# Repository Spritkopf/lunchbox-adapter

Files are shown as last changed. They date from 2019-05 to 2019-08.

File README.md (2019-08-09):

# Introduction

This is my interpretation of the *BrotboxErsatzPlatine* instrument adapter for the BMW K100. It is based on the circuit originally created by Maru (maru-labs.com).
Its purpose is to replace the original instrument unit of the BMW K100 (affectionately called *lunchbox* because of its distinctive shape) with 3rd party speedometer units. For more information have a look at maru-labs.com.
I extended the circuit according to my own needs and put together my own circuit board.

This project consists of the KiCAD design files for the schematic and PCB

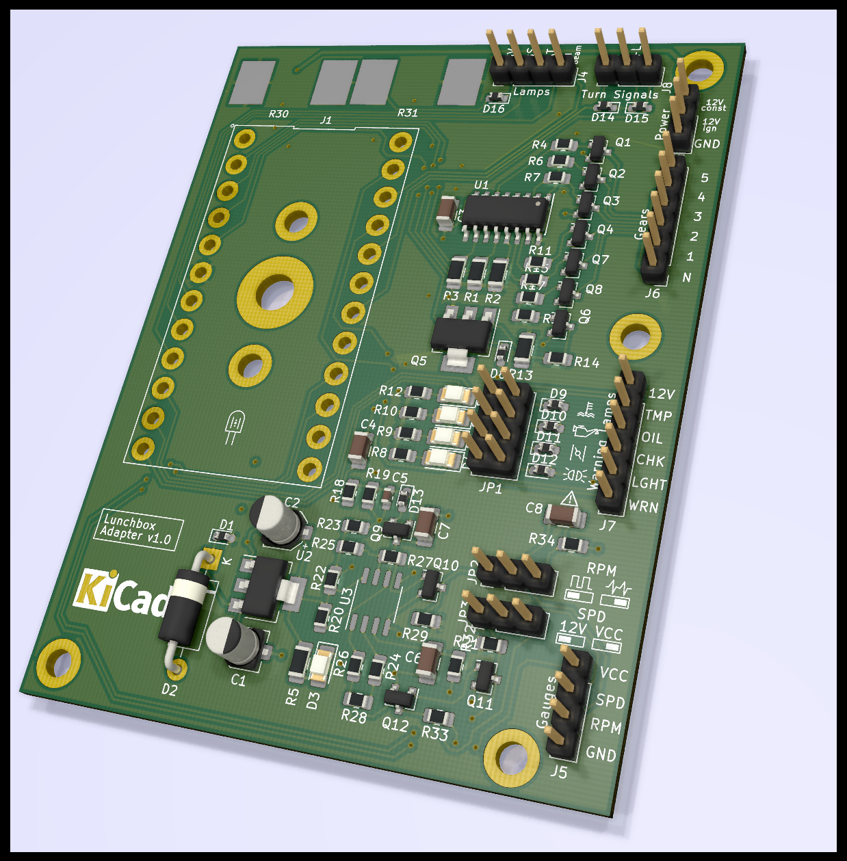
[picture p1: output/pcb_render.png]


# Features

* Plugs into the stock connector for the K100 instrument unit
* Convert signal of the original speed sensors to a square wave signal understood by most 3rd party speedos
* Conditioning of primary ignition coil RPM signal and conversion to square wave signal understood by most 3rd party speedos
* Provide excitation current for alternator
* Combine several of the information/warning lights to a common warning light output
* supports gear indicator (one wire for every gear)

## Speed signal voltage

The output voltage of the speed signal can be selected between 12V and a custom supply voltage at PIN1 (VCC) on the Gauges Connector (J5) by setting the jumper JP3 to the appropriate position

## RPM signal waveform

Depending on the type of tacho unit, the output waveform of the RPM signal can be selected between 12V Square wave (pulses to ground) and a sort of cleaned up raw ignition signal by setting jumper JP2 to the appropriate position. The square wave signal should be standard, the latter option is just there as an experiment.

## Warning lights

The warning lights for temperature (TMP), oil pressure (OIL), choke (CHK) and Light-test (LGHT) are displayed by individual LEDs on the board. Additionally, any number of them can be grouped together to a general warning lamp (WRN) if your dashboard has no space for this many lamps. Each of the 4 rows of Jumper JP1 can be bridged to select this warning signal to the general warning lamp. Please be aware that if only the general warning lamp is used you have no information on the source of the warning other than looking at the smd LEDs on the board.

# Credits

Thanks to maru (maru-labs.com) for the general idea. I re-used a lot of the circuit of the original BEP.
Thanks to user `robmack` from k100-forum.com from whom I stole the RPM conditioning circuit.

# No warranty

I created this as a hobby project as an experiment / exercise. I will not be responsible for any damage caused to your bike by using all of or parts of this circuit. Use at your own risk.

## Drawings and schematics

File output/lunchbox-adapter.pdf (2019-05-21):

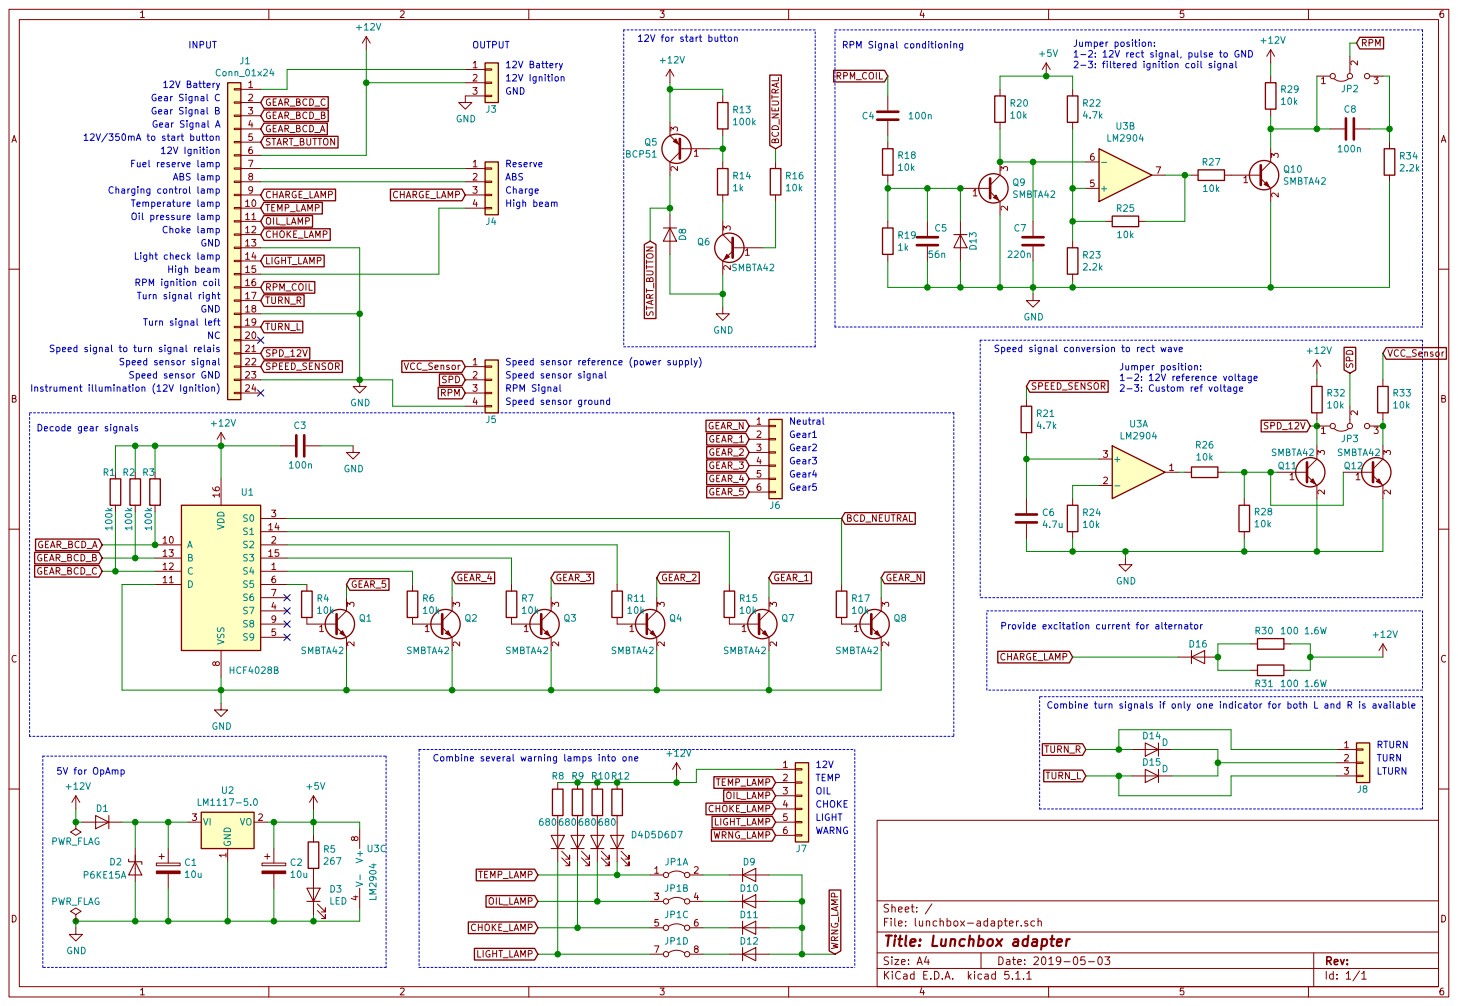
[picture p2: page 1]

1-2: 12V rect signal, pulse to GND

2-3: filtered ignition coil signal R19

Light check lamp
High beam
RPM ignition coil
Turn signal right GND

Turn signal left NC

Speed signal to turn signal relais

2 3 Q11 SMBTA42 Speed signal conversion to rect wave

Combine turn signals if only one indicator for both L and R is available D9 D10 D11 Combine several warning lamps into one

File: lunchbox-adapter.sch Sheet: /
Id: 1/1 Title: Lunchbox adapter

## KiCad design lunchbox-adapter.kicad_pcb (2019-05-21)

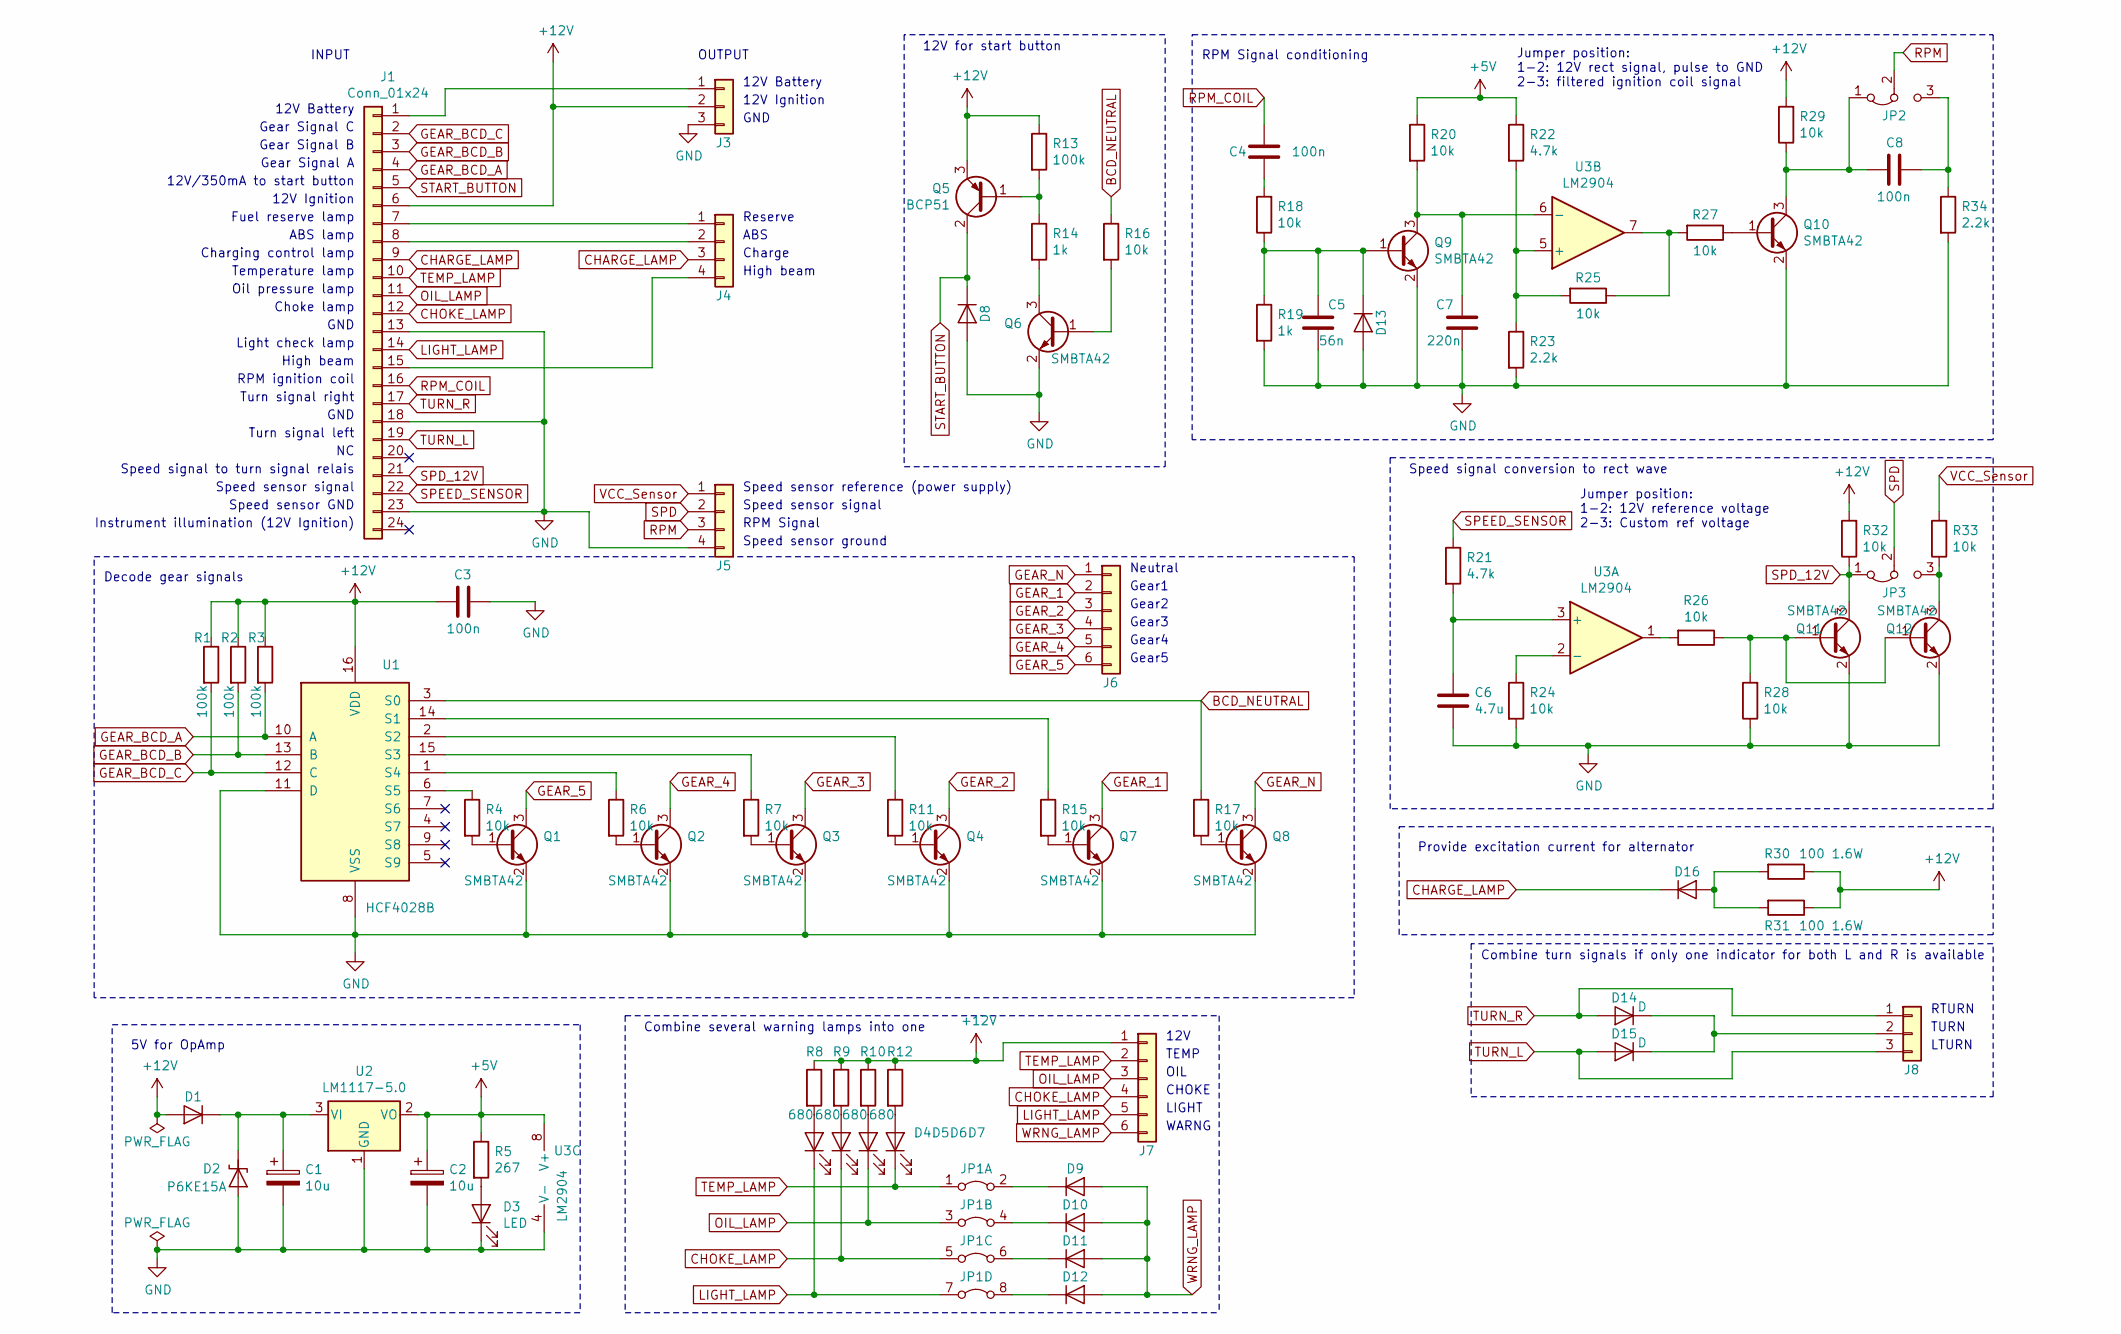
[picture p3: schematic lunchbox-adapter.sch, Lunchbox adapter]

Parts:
C1, C2: 10u; CP_Elec_4x5.8
C3, C4, C8: 100n; C_1206_3216Metric_Pad1.42x1.75mm_HandSolder
C5: 56n; C_0603_1608Metric_Pad1.05x0.95mm_HandSolder
C6: 4.7u; C_1206_3216Metric_Pad1.42x1.75mm_HandSolder
C7: 220n; C_1206_3216Metric_Pad1.42x1.75mm_HandSolder
D1, D8, D9, D10, D11, D12, D13, D14, D15, D16: D; D_0603_1608Metric_Pad1.05x0.95mm_HandSolder
D2: P6KE15A; D_DO-15_P12.70mm_Horizontal
D3, D4, D5, D6, D7: LED; LED_1206_3216Metric_Pad1.42x1.75mm_HandSolder
J1: Conn_01x24; DIP-24_866
J3, J8: Conn_01x03; PinHeader_1x03_P2.54mm_Vertical
J4, J5: Conn_01x03; PinHeader_1x04_P2.54mm_Vertical
J6, J7: Conn_01x06; PinHeader_1x06_P2.54mm_Vertical
JP1: Jumper_4x2; PinHeader_2x04_P2.54mm_Vertical
JP2, JP3: Jumper_3_Bridged12; PinHeader_1x03_P2.54mm_Vertical
Q1, Q2, Q3, Q4, Q6, Q7, Q8, Q9, Q10, Q11, Q12: SMBTA42; SOT-23
Q5: BCP51; SOT-223
R1, R2, R3, R13: 100k; R_1206_3216Metric_Pad1.42x1.75mm_HandSolder
R4, R6, R7, R11, R15, R16, R17, R18, R20, R24, R25, R26, R27, R28, R29, R32, R33: 10k; R_0805_2012Metric_Pad1.15x1.40mm_HandSolder
R5: 267; R_1206_3216Metric_Pad1.42x1.75mm_HandSolder
R8, R9, R10, R12: 680; R_0805_2012Metric_Pad1.15x1.40mm_HandSolder
R14, R19: 1k; R_0805_2012Metric_Pad1.15x1.40mm_HandSolder
R21, R22: 4.7k; R_0805_2012Metric_Pad1.15x1.40mm_HandSolder
R23, R34: 2.2k; R_0805_2012Metric_Pad1.15x1.40mm_HandSolder
R30, R31: 100 1.6W; 5020_resistor_thermal_pads
U1: HCF4028B; SOIC-16_3.9x9.9mm_P1.27mm
U2: LM1117-5.0; SOT-223-3_TabPin2
U3: LM2904; SO-8_3.9x4.9mm_P1.27mm

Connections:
+5V: C2.1, R5.1, R20.1, R22.1, U2.2 (VO), U3.8 (V+)
+12V: C3.1, D1.2 (A), J1.6, J3.2, J7.1, Q5.3 (E), R1.1, R2.1, R3.1, R8.1, R9.1, R10.1, R12.1, R13.1, R29.2, R30.1, R31.1, R32.2, U1.16 (VDD)
BCD_NEUTRAL: R16.1, R17.1, U1.3 (S0)
CHARGE_LAMP: D16.1 (K), J1.9, J4.3
CHOKE_LAMP: D5.1 (K), J1.12, J7.4, JP1.5
GEAR_1: J6.2, Q7.3 (C)
GEAR_2: J6.3, Q4.3 (C)
GEAR_3: J6.4, Q3.3 (C)
GEAR_4: J6.5, Q2.3 (C)
GEAR_5: J6.6, Q1.3 (C)
GEAR_BCD_A: J1.4, R3.2, U1.10 (A)
GEAR_BCD_B: J1.3, R2.2, U1.13 (B)
GEAR_BCD_C: J1.2, R1.2, U1.12 (C)
GEAR_N: J6.1, Q8.3 (C)
GND: C1.2, C2.2, C3.2, C5.2, C6.2, C7.2, D2.2 (A2), D3.1 (K), D8.2 (A), D13.2 (A), J1.13, J1.18, J1.23, J3.3, J5.4, Q1.2 (E), Q2.2 (E), Q3.2 (E), Q4.2 (E), Q6.2 (E), Q7.2 (E), Q8.2 (E), Q9.2 (E), Q10.2 (E), Q11.2 (E), Q12.2 (E), R19.2, R23.2, R24.2, R28.1, R34.2, U1.8 (VSS), U1.11 (D), U2.1 (GND), U3.4 (V-)
LIGHT_LAMP: D4.1 (K), J1.14, J7.5, JP1.7
unnamed: C1.1, D1.1 (K), D2.1 (A1), U2.3 (VI)
unnamed: C4.2, R18.2
unnamed: C5.1, D13.1 (K), Q9.1 (B), R18.1, R19.1
unnamed: C6.1, R21.2, U3.3 (+)
unnamed: C7.1, Q9.3 (C), R20.2, U3.6 (-)
unnamed: C8.1, JP2.3 (B), R34.1
unnamed: C8.2, JP2.1 (A), Q10.3 (C), R29.1
unnamed: D3.2 (A), R5.2
unnamed: D4.2 (A), R8.2
unnamed: D5.2 (A), R9.2
unnamed: D6.2 (A), R10.2
unnamed: D7.2 (A), R12.2
unnamed: D9.1 (K), JP1.2
unnamed: D10.1 (K), JP1.4
unnamed: D11.1 (K), JP1.6
unnamed: D12.1 (K), JP1.8
unnamed: D14.1 (K), D15.1 (K), J8.2
unnamed: D16.2 (A), R30.2, R31.2
unnamed: J1.1, J3.1
unnamed: J1.7, J4.1
unnamed: J1.8, J4.2
unnamed: J1.15, J4.4
unnamed: JP3.3 (B), Q12.3 (C), R33.1
unnamed: Q1.1 (B), R4.2
unnamed: Q2.1 (B), R6.2
unnamed: Q3.1 (B), R7.2
unnamed: Q4.1 (B), R11.2
unnamed: Q5.1 (B), R13.2, R14.1
unnamed: Q6.1 (B), R16.2
unnamed: Q6.3 (C), R14.2
unnamed: Q7.1 (B), R15.2
unnamed: Q8.1 (B), R17.2
unnamed: Q10.1 (B), R27.1
unnamed: Q11.1 (B), Q12.1 (B), R26.1, R28.2
unnamed: R4.1, U1.6 (S5)
unnamed: R6.1, U1.1 (S4)
unnamed: R7.1, U1.15 (S3)
unnamed: R11.1, U1.2 (S2)
unnamed: R15.1, U1.14 (S1)
unnamed: R22.2, R23.1, R25.2, U3.5 (+)
unnamed: R24.1, U3.2 (-)
unnamed: R25.1, R27.2, U3.7
unnamed: R26.2, U3.1
OIL_LAMP: D6.1 (K), J1.11, J7.3, JP1.3
RPM: J5.3, JP2.2 (C)
RPM_COIL: C4.1, J1.16
SPD: J5.2, JP3.2 (C)
SPD_12V: J1.21, JP3.1 (A), Q11.3 (C), R32.1
SPEED_SENSOR: J1.22, R21.1
START_BUTTON: D8.1 (K), J1.5, Q5.2 (C)
TEMP_LAMP: D7.1 (K), J1.10, J7.2, JP1.1
TURN_L: D15.2 (A), J1.19, J8.3
TURN_R: D14.2 (A), J1.17, J8.1
VCC_Sensor: J5.1, R33.2
WRNG_LAMP: D9.2 (A), D10.2 (A), D11.2 (A), D12.2 (A), J7.6

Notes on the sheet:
12V Battery
Gear Signal C
Gear Signal B
Gear Signal A
12V/350mA to start button
12V Ignition
Fuel reserve lamp
ABS lamp
Charging control lamp
Temperature lamp
Oil pressure lamp
Choke lamp
GND
Light check lamp
High beam
RPM ignition coil
Turn signal right
Turn signal left
Speed signal to turn signal relais
Speed sensor signal
Speed sensor GND
Instrument illumination (12V Ignition)
Speed signal conversion to rect wave
INPUT
OUTPUT
Combine turn signals if only one indicator for both L and R is available
Combine several warning lamps into one
12V for start button
Provide excitation current for alternator
Decode gear signals
5V for OpAmp
RPM Signal conditioning
Jumper position: 1-2: 12V rect signal, pulse to GND 2-3: filtered ignition coil signal
Gear1
Gear2
Gear3
Gear4
Gear5
Neutral
Speed sensor reference (power supply)

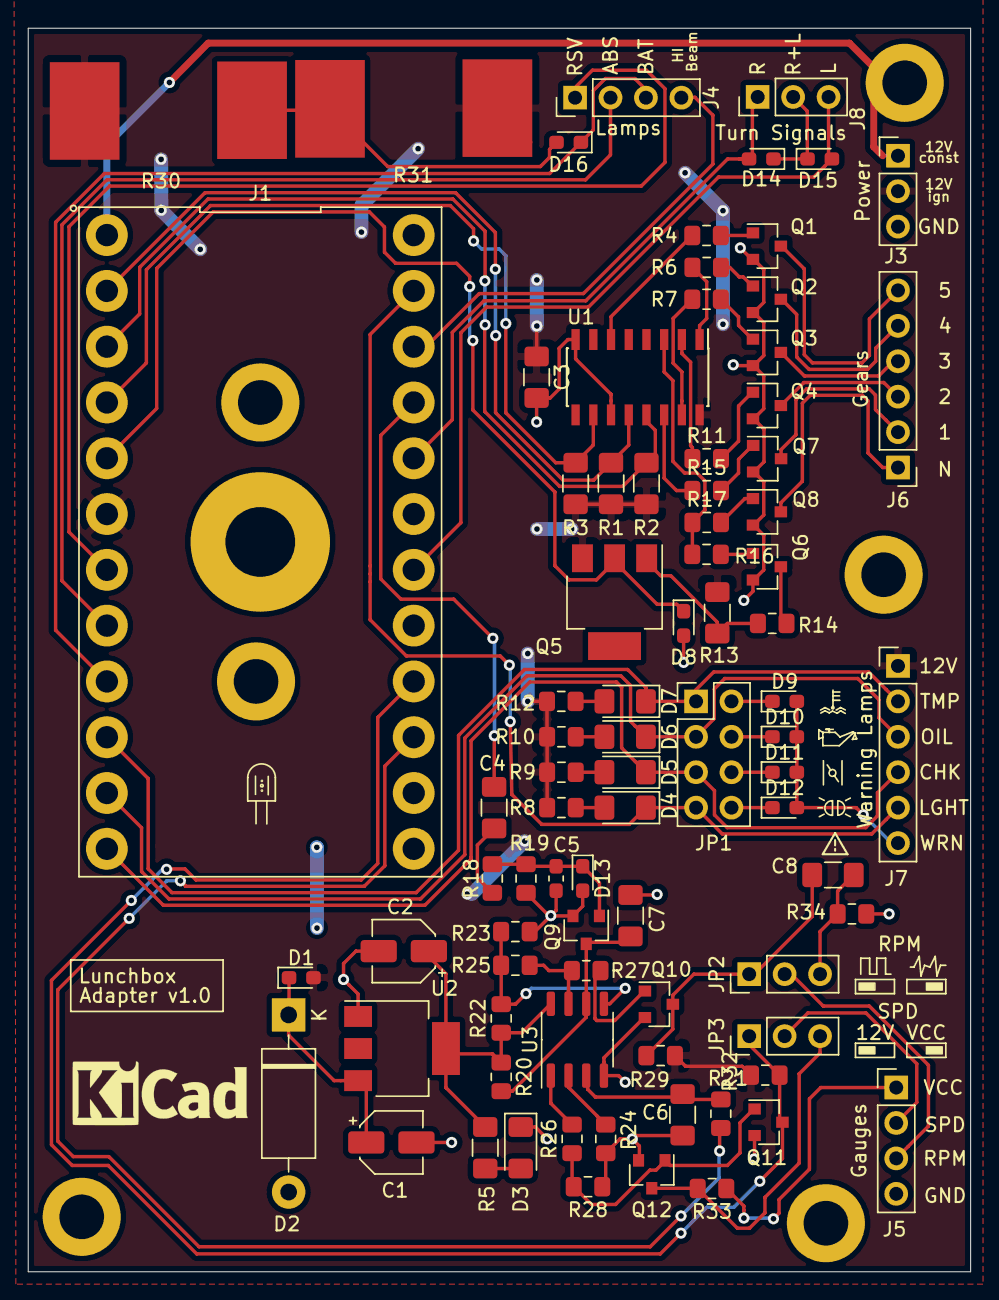
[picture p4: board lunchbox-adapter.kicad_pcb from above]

Board: 2 copper layers, 67.6 x 89.2 mm, 83 parts (0 on the bottom side), 71 nets.

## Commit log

2019-04-30 add empty kicad project
    [bep.kicad_pcb, bep.sch]
2019-05-02 add local symbol library, begin schematic
    [bep.sch]
2019-05-03 first version of schematic finished
    [bep.sch, power_supply.sch]
2019-05-03 add TSV diode to library
    [bep.sch]
2019-05-03 finished logic of schematic
    [bep.sch]
2019-05-06 finalized schematic
    [bep.sch, power_supply.sch]
2019-05-10 output signals grouped to several connectors
    [bep.kicad_pcb, bep.sch]
2019-05-10 begin pcb
    [bep.kicad_pcb, bep.sch]
2019-05-16 finished pcb, review candidate
    [bep.kicad_pcb, bep.sch]
2019-05-16 renamed project
    [lunchbox-adapter.kicad_pcb, lunchbox-adapter.sch]
2019-05-17 finished pcb design
    [lunchbox-adapter.kicad_pcb, lunchbox-adapter.sch]
2019-05-17 add schematic PDF
    [lunchbox-adapter.kicad_pcb]
2019-05-20 change power resitor footprints, cleanup
    [lunchbox-adapter.kicad_pcb, lunchbox-adapter.sch]
2019-05-21 cleanup mounting holes
    [lunchbox-adapter.kicad_pcb]
2019-05-21 final; add gerber files for manufacturing
    [lunchbox-adapter-B_Cu.gbr, lunchbox-adapter-B_Mask.gbr, lunchbox-adapter-B_SilkS.gbr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]
2025-12-15 add BOM and 3d printed housing CAD files
